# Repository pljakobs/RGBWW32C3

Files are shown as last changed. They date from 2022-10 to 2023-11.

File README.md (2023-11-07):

# RGBWW32C3
## a new, smaller RGBWW controller built around the ESP32C3M0 module

This is based on the original design by Patrick Jahns but modified to fit into a much smaller footprint and use the much more capable ESP32 Platform - in this case the C3 Wroom 02 module.

The ESP32C3 is a risc-v based implementation of the ESP32 µC family, providing much the same peripherals as the xtensa based chips, but at a much lower price point.

The design is straight forward:

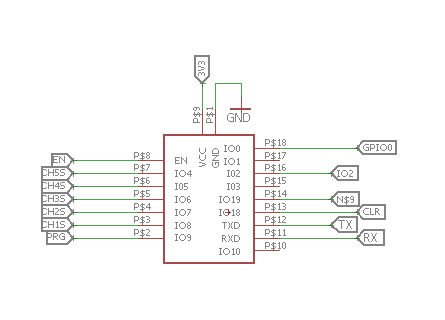
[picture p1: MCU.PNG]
ESP32C3 module schemantic


According to the [ESP32C3Wroom02 Datasheet](https://www.espressif.com/sites/default/files/documentation/esp32-c3-wroom-02_datasheet_en.pdf) the strapping pins are
|Pin|Default|SPI Boot (normal)|Download Boot (prg)|
|IO2|N/A|HIGH|HIGH|
|IO8|N/A|ignore|HIGH|
|IO9|weak pullup|HIGH|LOW|

Therefore, IO2 and IO8 need to be pulled high, IO9 should be pulled high for normal operation and pulled to GND for programming / Booting
That results in the following strapping / switching schematic:

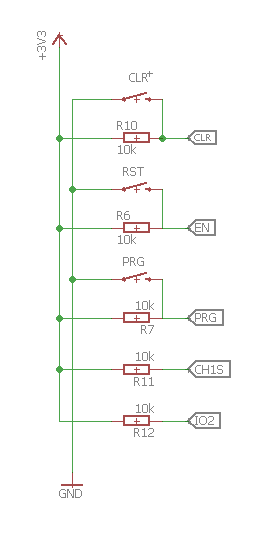
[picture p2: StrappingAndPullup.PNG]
ESP32C3 pin strapping


The output stage has, from a schematic point of view, mostly remained unchanged (as if there was a lot to change on driving N-Channel MOSFETS). The actual MOSFETs however have been replaced with much smaller packaged types. Currently, I'm looking at Alpha&Omega devices AO4808 or better (there are some in the family that go up to 11.5A Drain current per channel and 30V VDS which would make the mini a fully featured replacement for the original controller, although the TO92 IRFZ44N theoretically could drive 49A of drain source current, but the design was never built to provide that).

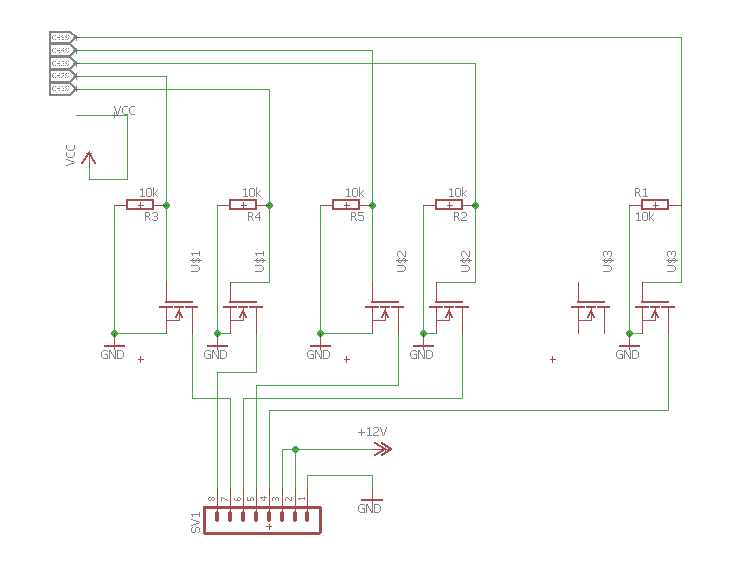
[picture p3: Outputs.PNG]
Lightinator Mini output stage


One of the biggest changes from the original design by Patrick and the last Version (green boards) was that I ditched the 3rd party DC/DC modules in favour of a power converter on board, designed with [TI Power Designer Webbench](https://webench.ti.com/power-designer/switching-regulator?powerSupply=0), a tool that I have come to value a lot. 
This time, the requirement was to make the power converter smaller but no less powerful (still capable of pushing up to 600mA at 3.3V but optimized for 200mA)

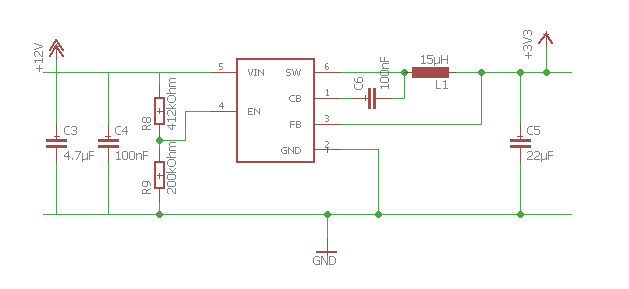
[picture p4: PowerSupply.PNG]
the switching power supply on board


The last bit of the schematic is to programming port. This device will not be easily programmed "at home" as it should, normally, come without a header installed (which just now makes me think why I have a PRG button on it after all, I should remove that). The programming port is six pads on the bottom of the board, fit to mount a 1/20" SMD pin header that matches the six pin cable of the [esp_prog](https://docs.espressif.com/projects/espressif-esp-iot-solution/en/latest/hw-reference/ESP-Prog_guide.html). The intention is to have a printed jig where the boards can be initially programmed, everything after that should be done OTA

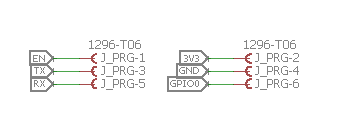
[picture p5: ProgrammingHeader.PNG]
programming port


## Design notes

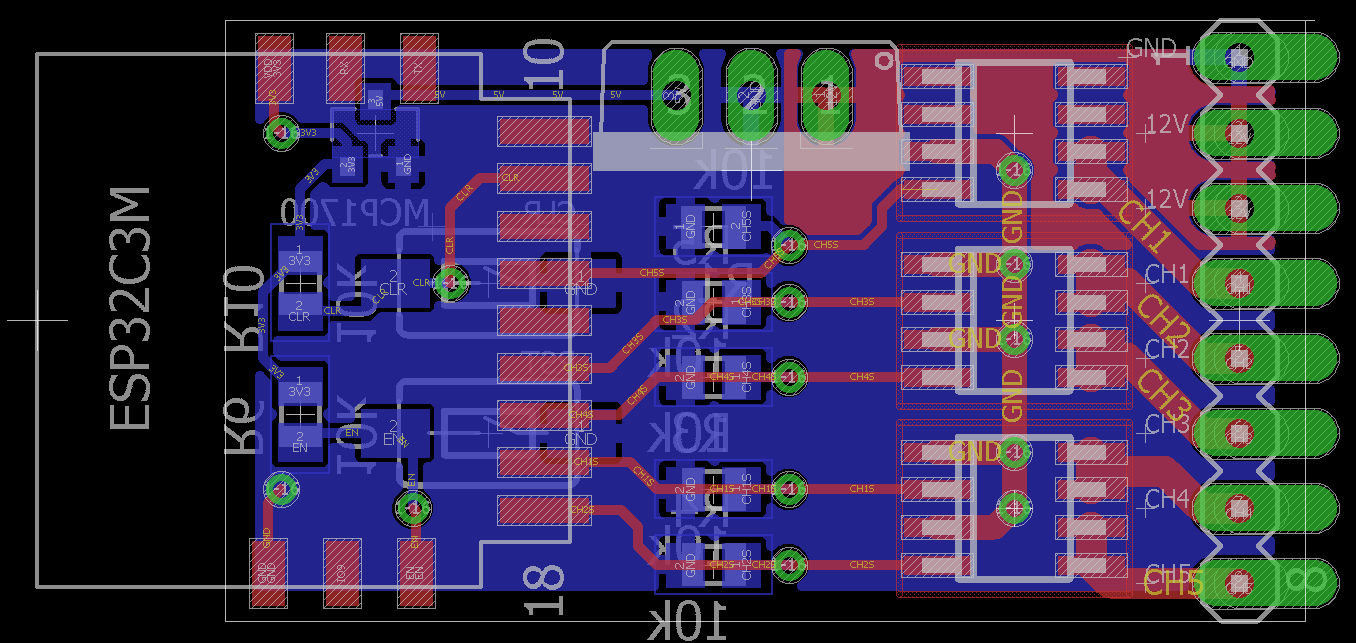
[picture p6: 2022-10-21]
platine.PNG

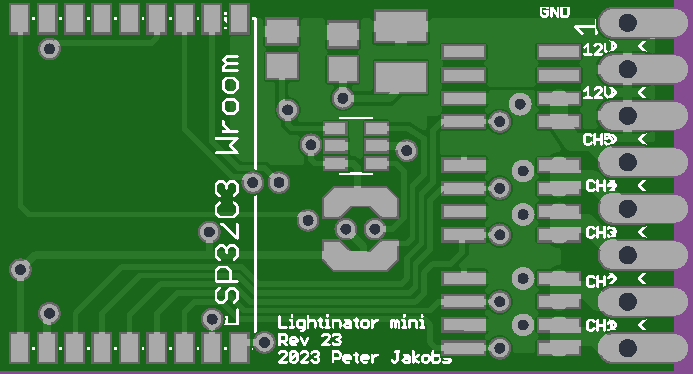
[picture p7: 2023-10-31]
RGBWW32C3_top.PNG

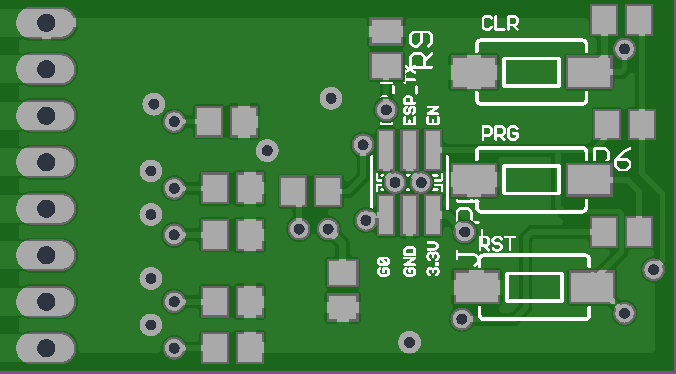
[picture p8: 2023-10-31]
RGBWW32C3_bottom.PNG

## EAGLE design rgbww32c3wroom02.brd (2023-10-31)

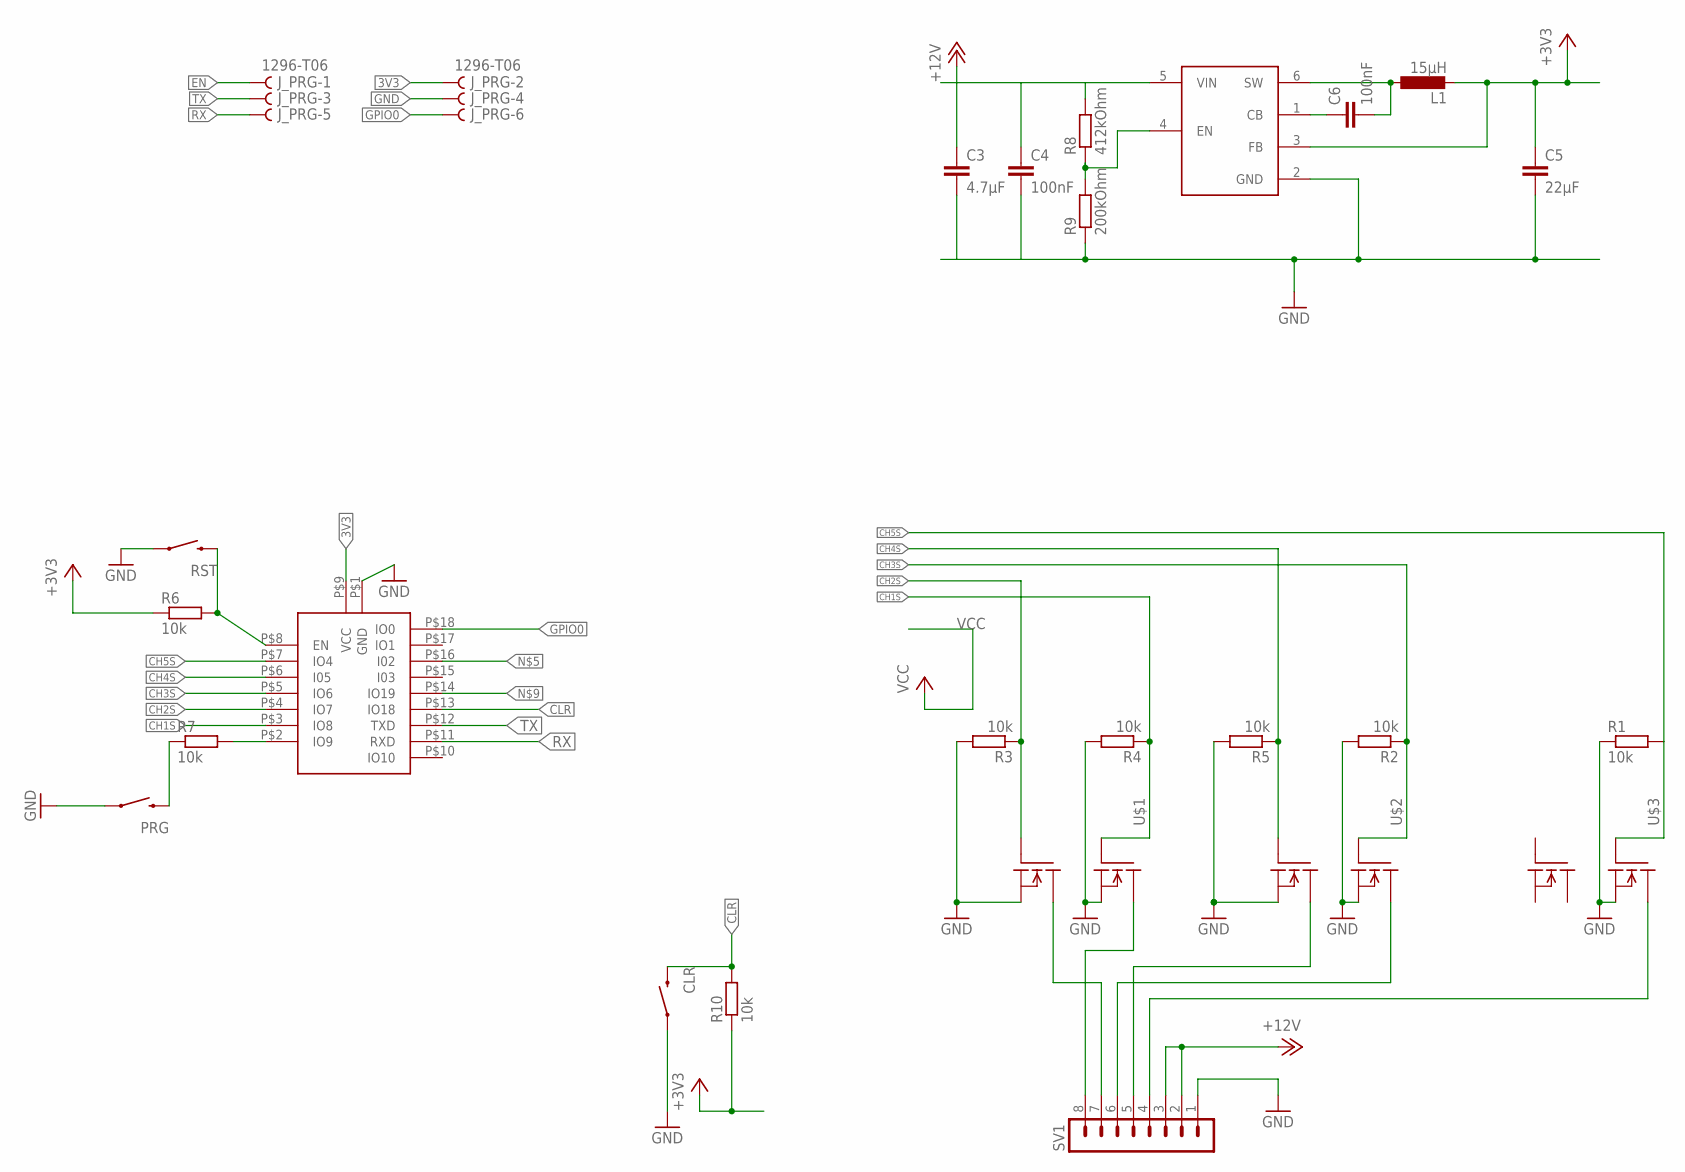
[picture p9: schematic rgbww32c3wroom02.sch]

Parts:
C3: 4.7µF; C1210
C4, C6: 100nF; C0805
C5: 22µF; C0805
CLR: SWITCH-MOMENTARY-2SMD-1101NE; TACTILE-SWITCH-1101NE
J_PRG: 1296-T06; 06
L1: 15µH; LPS4018
PRG: SWITCH-MOMENTARY-2SMD-1101NE; TACTILE-SWITCH-1101NE
R1, R2, R3, R4, R5, R6, R7, R10: 10k; R0805
R8: 412kOhm; M0805
R9: 200kOhm; M0805
RST: SWITCH-MOMENTARY-2SMD-1101NE; TACTILE-SWITCH-1101NE
SV1: MA08-1
U$1, U$2, U$3: AOD4806; SO08
U$5: ESP32C3WROOM02; SMD
U$6: TPS5604030; SOT23-6

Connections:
3V3: C5.1, J_PRG.2, L1.2, R6.1, R10.1, U$5.P$9 (VCC), U$6.3 (FB)
12V: C3.1, C4.1, R8.2, SV1.2, SV1.3, U$6.5 (VIN)
BOOT: C6.1, U$6.1 (CB)
CH1: SV1.8, U$1.5 (D), U$1.6 (D)
CH1S: R4.1, U$1.4 (G), U$5.P$3 (IO8)
CH2: SV1.7, U$1.7 (D1), U$1.8 (D1)
CH2S: R3.1, U$1.2 (G1), U$5.P$4 (IO7)
CH3: SV1.6, U$2.5 (D), U$2.6 (D)
CH3S: R2.1, U$2.4 (G), U$5.P$5 (IO6)
CH4: SV1.5, U$2.7 (D1), U$2.8 (D1)
CH4S: R5.1, U$2.2 (G1), U$5.P$6 (I05)
CH5: SV1.4, U$3.5 (D), U$3.6 (D)
CH5S: R1.2, U$3.4 (G), U$5.P$7 (IO4)
CLR: CLR.2, R10.2, U$5.P$13 (IO18)
EN: J_PRG.1, R6.2, RST.2, U$5.P$8 (EN)
EN_P: R8.1, R9.2, U$6.4 (EN)
GND: C3.2, C4.2, C5.2, CLR.1, J_PRG.4, PRG.1, R1.1, R2.2, R3.2, R4.2, R5.2, R9.1, RST.1, SV1.1, U$1.1 (S1), U$1.3 (S), U$2.1 (S1), U$2.3 (S), U$3.3 (S), U$5.P$1 (GND), U$6.2 (GND)
GPIO0: J_PRG.6, U$5.P$18 (IO0)
PRG: R7.2, U$5.P$2 (IO9)
PRG1: PRG.2, R7.1
RX: J_PRG.5, U$5.P$11 (RXD)
SW: C6.2, L1.1, U$6.6 (SW)
TX: J_PRG.3, U$5.P$12 (TXD)

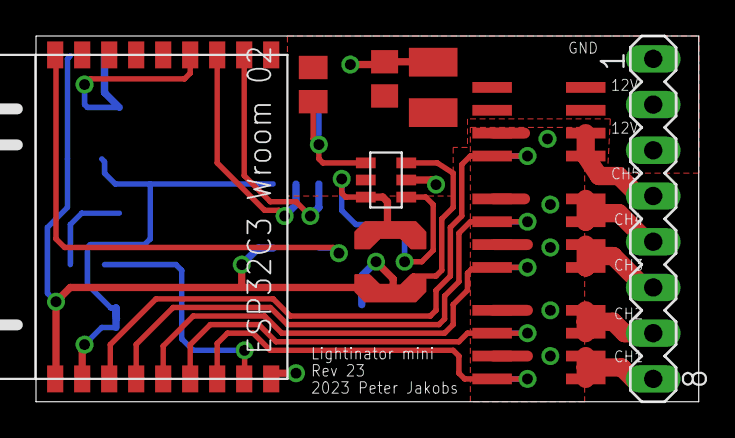
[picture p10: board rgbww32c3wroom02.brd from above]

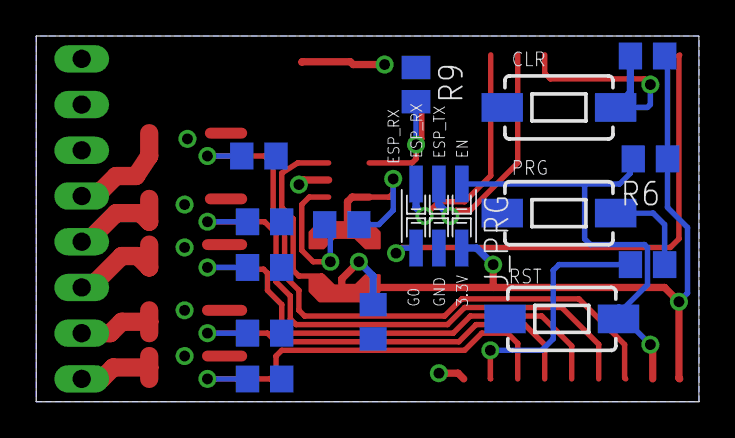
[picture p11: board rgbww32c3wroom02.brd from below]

Board: 2 copper layers, 36.8 x 20.3 mm, 25 parts (15 on the bottom side), 23 nets.

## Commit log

2022-10-22 adjusted channel names
    [rgbww32c3.brd, rgbww32c3.sch]
2022-11-07 initial testing version
    programming the ESP32 now works using an esp_prog. It does require to pull GPIO9 low, hence the extra PRG button. The auto programming function of other ESP models (GPIO0) does not work on the C3, it seems.
    [rgbww32c3.brd, rgbww32c3.sch]
2022-11-07 had the 12V->5V converter backwards
    [rgbww32c3.brd]
2022-11-07 minor routing error
    [rgbww32c3.brd]
2022-11-07 few routing corrections to better avoid short circuits
    [rgbww32c3.brd, rgbww32c3.sch]
2023-09-06 new layout for wroom02 module
    reworked the layout to use the ESP Wroom 02 module which should be easier to solder and route
    [rgbww32c3wroom02.brd, rgbww32c3wroom02.sch]
2023-09-06 moved the 3.3V reg to clean up things a bit. Not sure if it will be in the way of the 5V VRs inductance
    [rgbww32c3wroom02.brd]
2023-09-06 some corrections before production
    [rgbww32c3wroom02.brd, rgbww32c3wroom02.sch]
2023-10-30 built local voltage reg
2023-10-30 added local switching voltage regulator
    [rgbww32c3wroom02.brd, rgbww32c3wroom02.sch]
2023-10-30 resolved two minor mistakes
    The footprint for L1 still needs to get it's solder mask taken off.
    [rgbww32c3wroom02.brd]
2023-10-30 updated solder mask retraction
2023-10-31 added gerber pictures
    [rgbww32c3wroom02.brd, rgbww32c3wroom02.sch]
2023-10-31 small changes on the 12V side
    moved the input caps so that the 12V pins are now oriented towards the switching controller. nothing major but might get a wee bit better filtering due to smaller loop area
    [rgbww32c3wroom02.brd]
2023-11-07 removed confusing old boards
    [rgbww32c3.brd, rgbww32c3.sch]

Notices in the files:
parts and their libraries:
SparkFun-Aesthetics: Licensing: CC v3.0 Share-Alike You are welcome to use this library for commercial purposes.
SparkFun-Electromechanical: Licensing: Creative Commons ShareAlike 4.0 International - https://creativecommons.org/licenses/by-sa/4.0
